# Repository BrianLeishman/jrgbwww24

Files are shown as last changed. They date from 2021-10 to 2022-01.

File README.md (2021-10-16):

# jrgbwww24 - esp8266 board for controlling RGB W WW 24V LED strips

This PCB is designed to take esp8266 NodeMCU boards and allow them to control 24V LED strips that have RGB, cool white, and warm white LEDs.

This board is also designed to power the esp8266 board with 5V, so no USB connection is needed. Another cool feature is that this board has a 5V fan header (like a computer motherboard would), so you can plug in a fan like [this Noctua one](https://amzn.to/3mTPDOA) in case some cooling is needed.

PCB dimensions and screw holes are designed to be an exact match to a Raspberry Pi 4, for compatibility with Pi accessories like enclosures or cases.

## Heads up!

The circuits for each color channel are inverted, so make sure you specify `inverted: True` in your esphome config, for example. You can check a full example config [below](#example-esphome-config).

# Renders

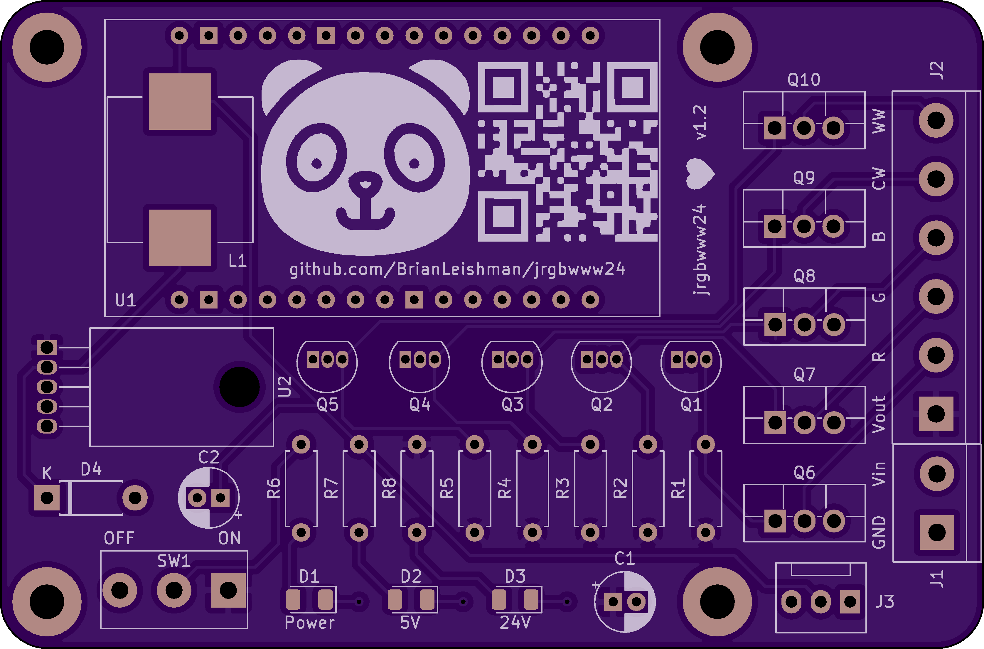
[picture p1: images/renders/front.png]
Front


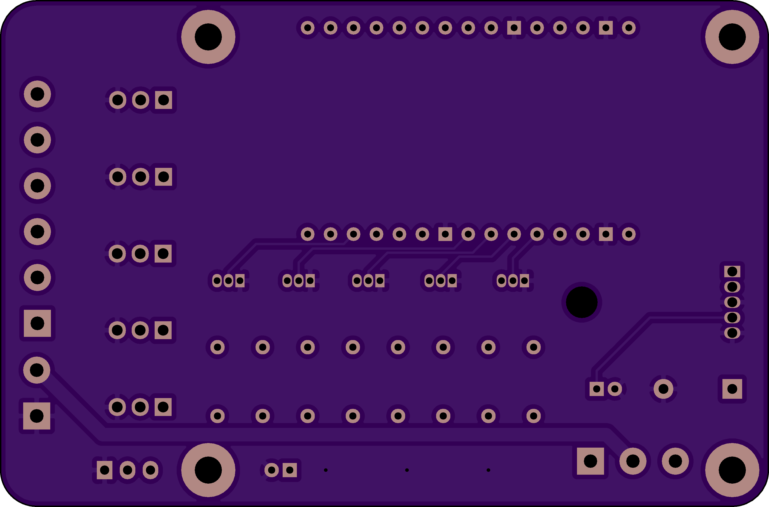
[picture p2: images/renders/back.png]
Back


# Example esphome config

```yaml
esphome:
  name: kitchen-under-cabinet-1
  platform: ESP8266
  board: nodemcuv2

# Enable logging
logger:

# Enable Home Assistant API
api:
  password: "mypassword"

ota:
  password: "mypassword"

wifi:
  ssid: "My Internet"
  password: "wifi password"
  manual_ip:
    static_ip: 192.168.1.50
    gateway: 192.168.1.1
    subnet: 255.255.255.0

  # Enable fallback hotspot (captive portal) in case wifi connection fails
  ap:
    ssid: "Rgbww Fallback Hotspot"
    password: "ZiNHD3xPr345s7UL"

captive_portal:

#RGB CoolWhite WarmWhite
output:
  - platform: esp8266_pwm
    pin: 4
    frequency: 1000 Hz
    id: pwm_r
    inverted: True
  - platform: esp8266_pwm
    pin: 14
    frequency: 1000 Hz
    id: pwm_g
    inverted: True
  - platform: esp8266_pwm
    pin: 12
    frequency: 1000 Hz
    id: pwm_b
    inverted: True
  - platform: esp8266_pwm
    pin: 13
    frequency: 1000 Hz
    id: pwm_cw
    inverted: True
  - platform: esp8266_pwm
    pin: 15
    frequency: 1000 Hz
    id: pwm_ww
    inverted: True
light:
  - platform: rgbww
    name: "K Light"
    red: pwm_r
    green: pwm_g
    blue: pwm_b
    cold_white: pwm_cw
    warm_white: pwm_ww
    cold_white_color_temperature: 6500 K
    warm_white_color_temperature: 3000 K
    color_interlock: True
```

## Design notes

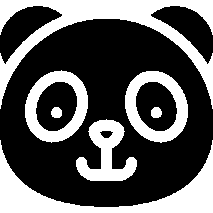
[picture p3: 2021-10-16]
panda.bmp

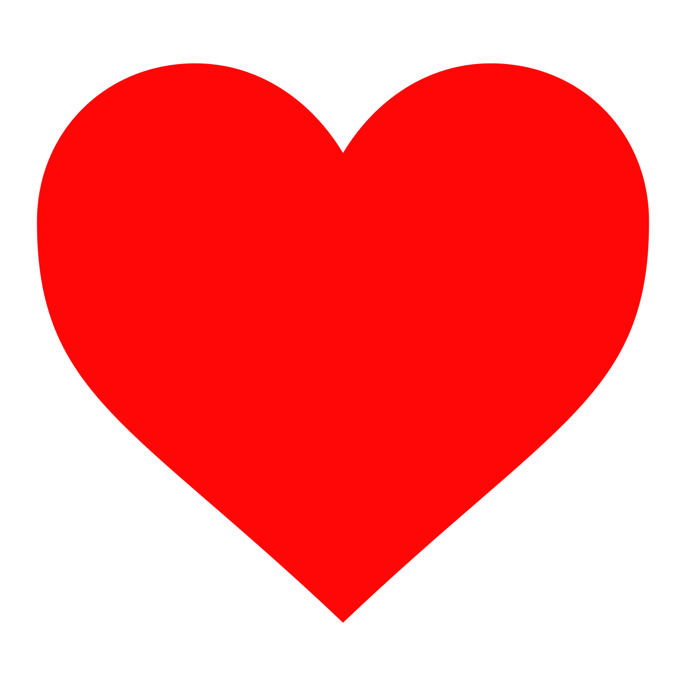
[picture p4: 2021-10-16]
1200px-Heart_corazón.svg.png

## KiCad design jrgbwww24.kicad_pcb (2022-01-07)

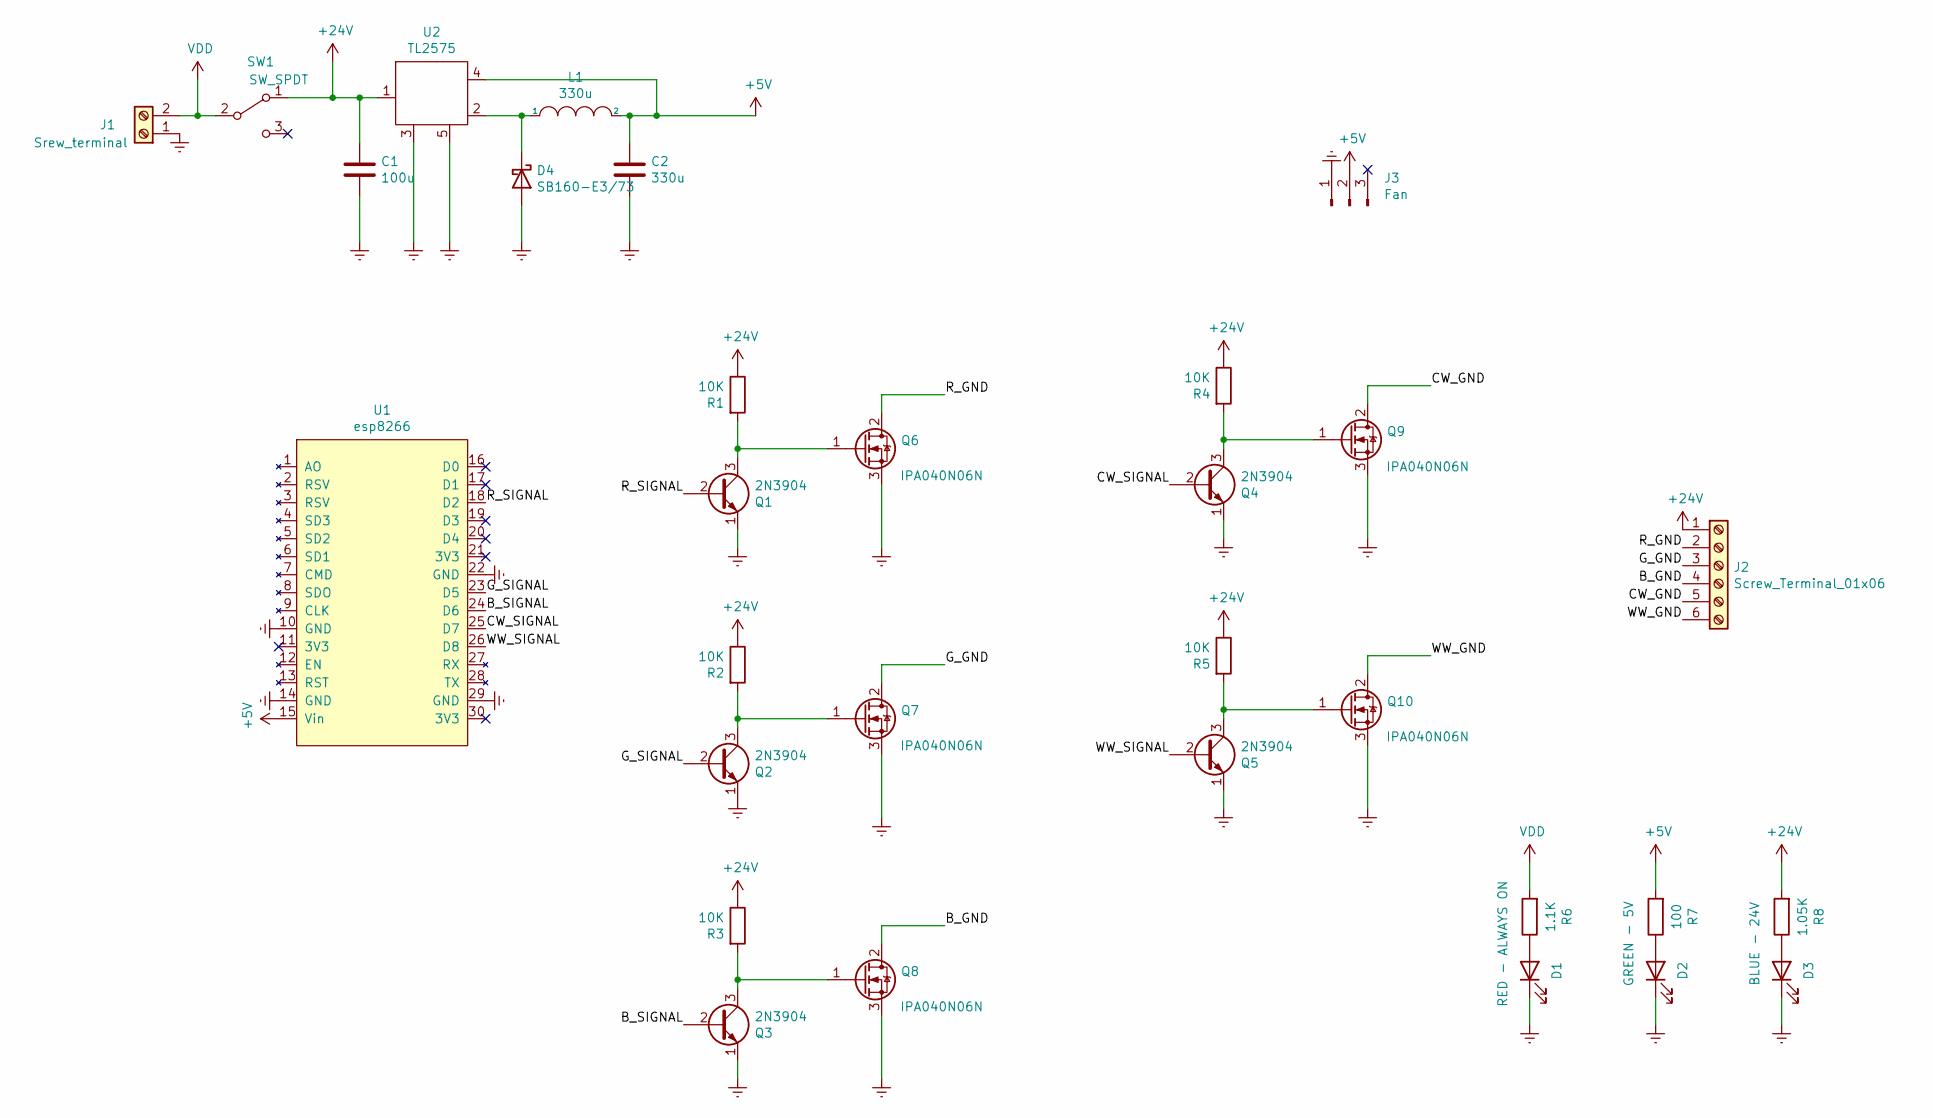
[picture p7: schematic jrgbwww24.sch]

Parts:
C1: 100u; CP_Radial_D5.0mm_P2.00mm
C2: 330u; CP_Radial_D5.0mm_P2.00mm
D1: RED - ALWAYS ON; LED_1206_3216Metric
D2: GREEN - 5V; LED_1206_3216Metric
D3: BLUE - 24V; LED_1206_3216Metric
D4: SB160-E3/73; D_DO-41_SOD81_P7.62mm_Horizontal
J1: Srew_terminal; TerminalBlock_bornier-2_P5.08mm
J2: Screw_Terminal_01x06; TerminalBlock_bornier-6_P5.08mm
J3: Fan; FanPinHeader_1x03_P2.54mm_Vertical
L1: 330u; L_Wuerth_WE-PD-Typ-LS_Handsoldering
Q1, Q2, Q3, Q4, Q5: 2N3904; TO-92_Inline
Q6, Q7, Q8, Q9, Q10: IPA040N06N; TO-220F-3_Vertical
R1, R2, R3, R4, R5: 10K; R_Axial_DIN0207_L6.3mm_D2.5mm_P7.62mm_Horizontal
R6: 1.1K; R_Axial_DIN0207_L6.3mm_D2.5mm_P7.62mm_Horizontal
R7: 100; R_Axial_DIN0207_L6.3mm_D2.5mm_P7.62mm_Horizontal
R8: 1.05K; R_Axial_DIN0207_L6.3mm_D2.5mm_P7.62mm_Horizontal
SW1: SW_SPDT; 1P2T SPDT
U1: esp8266; KeeYees ESP8266 ESP-12E
U2: TL2575; TO-220-5_Horizontal_TabDown

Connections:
+5V: C2.1, J3.2, L1.2, R7.2, U1.15 (Vin), U2.4
+24V: C1.1, J2.1, R1.1, R2.1, R3.1, R4.1, R5.1, R8.2, SW1.1 (A), U2.1
/B_GND: J2.4, Q8.2 (D)
/B_SIGNAL: Q3.2 (B), U1.24 (D6)
/CW_GND: J2.5, Q9.2 (D)
/CW_SIGNAL: Q4.2 (B), U1.25 (D7)
/G_GND: J2.3, Q7.2 (D)
/G_SIGNAL: Q2.2 (B), U1.23 (D5)
/R_GND: J2.2, Q6.2 (D)
/R_SIGNAL: Q1.2 (B), U1.18 (D2)
/WW_GND: J2.6, Q10.2 (D)
/WW_SIGNAL: Q5.2 (B), U1.26 (D8)
Earth: C1.2, C2.2, D1.1 (K), D2.1 (K), D3.1 (K), D4.2 (A), J1.1, J3.1, Q1.1 (E), Q2.1 (E), Q3.1 (E), Q4.1 (E), Q5.1 (E), Q6.3 (S), Q6.5 (S), Q6.6 (S), Q6.7 (S), Q7.3 (S), Q7.5 (S), Q7.6 (S), Q7.7 (S), Q8.3 (S), Q8.5 (S), Q8.6 (S), Q8.7 (S), Q9.3 (S), Q9.5 (S), Q9.6 (S), Q9.7 (S), Q10.3 (S), Q10.5 (S), Q10.6 (S), Q10.7 (S), U1.10 (GND), U1.14 (GND), U1.22 (GND), U1.29 (GND), U2.3, U2.5
unnamed: D1.2 (A), R6.1
unnamed: D2.2 (A), R7.1
unnamed: D3.2 (A), R8.1
unnamed: D4.1 (K), L1.1, U2.2
unnamed: Q1.3 (C), Q6.1 (G), R1.2
unnamed: Q2.3 (C), Q7.1 (G), R2.2
unnamed: Q3.3 (C), Q8.1 (G), R3.2
unnamed: Q4.3 (C), Q9.1 (G), R4.2
unnamed: Q5.3 (C), Q10.1 (G), R5.2
VDD: J1.2, R6.2, SW1.2 (B)

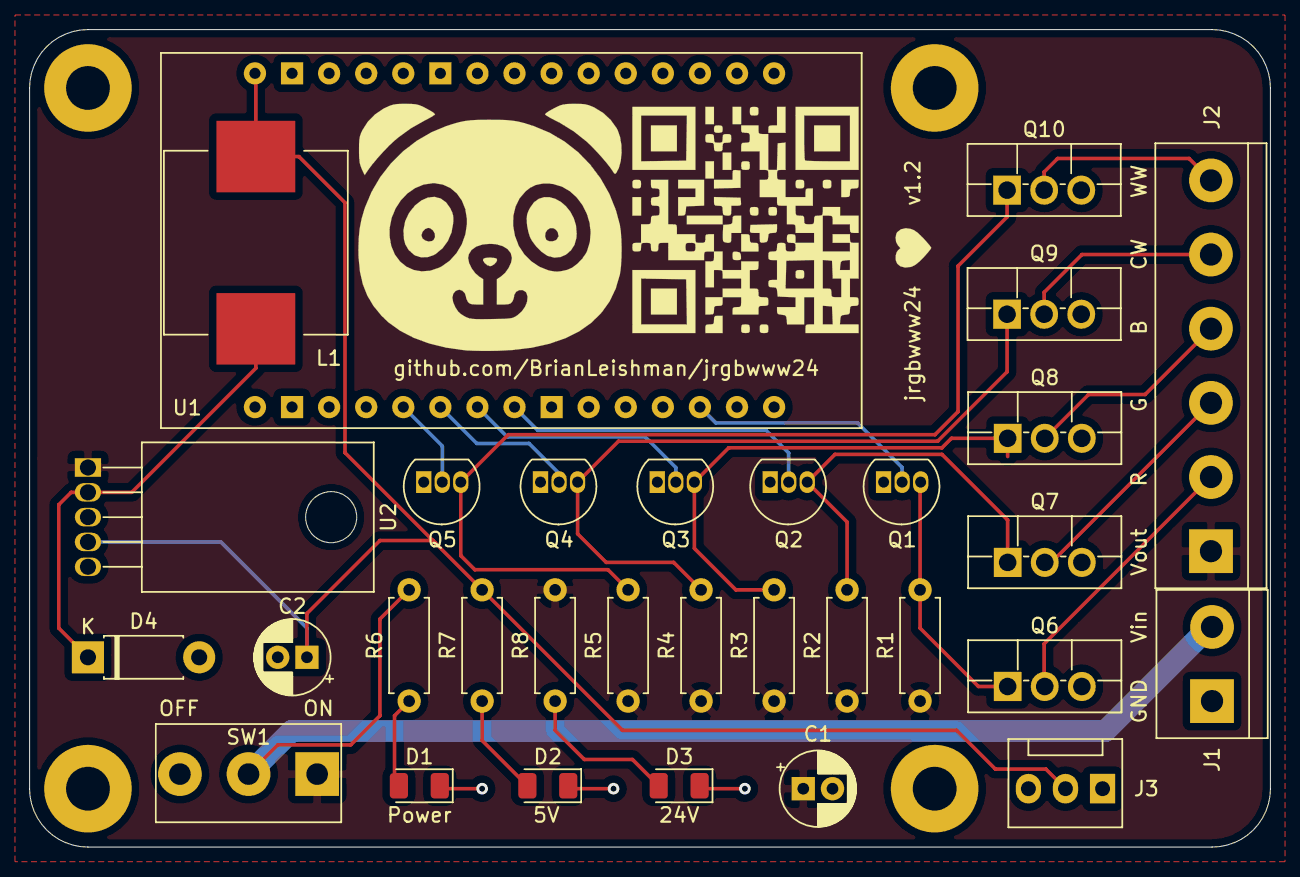
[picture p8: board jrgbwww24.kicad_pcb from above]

Board: 2 copper layers, 85.0 x 56.0 mm, 31 parts (0 on the bottom side), 23 nets.

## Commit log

2021-09-21 labeled connections
    [jrgbwww24.sch]
2021-09-23 schmea refactor
    [jrgbwww24.sch]
2021-09-23 fixed all erc errors, updated esp symbol
    [jrgbwww24.sch]
2021-09-28 some footprints
    [jrgbwww24.sch]
2021-10-07 gerber file
    [jrgbwww24-B_Cu.gbr, jrgbwww24-B_Mask.gbr, jrgbwww24-B_Paste.gbr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]
2021-10-07 gerber files and drill files
    [jrgbwww24-B_Cu.gbr, jrgbwww24-B_Mask.gbr, jrgbwww24-B_Paste.gbr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]
2021-10-16 fixed footprints, schematics
    [jrgbwww24.kicad_pcb, jrgbwww24.sch]
2021-10-16 improved 5v, fan header
    [jrgbwww24.kicad_pcb, jrgbwww24.sch]
2021-10-16 gerber files, updated renders
    [jrgbwww24-B_Cu.gbr, jrgbwww24-B_Mask.gbr, jrgbwww24-B_Paste.gbr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]
2022-01-07 fixed 5 v power supply
    [jrgbwww24-B_Cu.gbr, jrgbwww24-B_Mask.gbr, jrgbwww24-B_Paste.gbr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]
